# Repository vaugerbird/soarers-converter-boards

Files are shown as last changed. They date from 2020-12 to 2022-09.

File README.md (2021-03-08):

# Soarers-Dongle

Like the description says, this is just a simple dongle adapter for converting an IBM Model M with RJ45 plug to USB through various methods. I whiped up the PCBs in about an hour each, so there might be errors in the PCB design. If there is, file an issue report and I'll fix it right away! Also, please do not plug an ethernet cord into the dongle or keypad, as it might do weird things (or nothing at all)! 

<br>

I've included the EAGLE PCB files for all of the boards, their respective BOMs, and all of Soarer's files relevent to the PCBs. I <i><b>in no way take</b></i> responsibity for creating or modifying the files in the soarers-files folder, all credit goes to Soarer. If you want more info on the original project, check out Soarer's guide [here](https://deskthority.net/viewtopic.php?f=7&t=2510&start=).

TODO
------
To view what needs to be done and what has been done, check out my [Trello](https://trello.com/b/eKjTxFPa/soarers-converter-boards) board!

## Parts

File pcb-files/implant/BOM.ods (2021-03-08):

Part Description | Part # | Mouser # | Digikey # | Footprint | $/Unit | Qty # | Board ID # | Mouser Link | Digikey Link | Notes
ATMega32u4 | ATMEGA32U4-MU | 556-ATMEGA32U4-MU | ATMEGA32U4-AURCT-ND | QFN-44 | $3.98 | 1 | N/A | Mouser (https://www.mouser.com/ProductDetail/Microchip-Technology-Atmel/ATMEGA32U4-MU?qs=JV7lzlMm3yJYRpi0cY3cKw%3D%3D) | Digikey (https://www.digikey.com/en/products/detail/microchip-technology/ATMEGA32U4-AUR/2238241) | Had to change from AU to MU to fit PCB
USB C Port | USB4085-GF-A | N/A | 2073-USB4085-GF-ACT-ND | N/A | $1.34 | 1 | USB-C | N/A | Digikey (https://www.digikey.com/en/products/detail/gct/USB4085-GF-A/9859662)
5.1k Pull-Down Resistor | CRCW06035K10KKEATR | 71-CRCW06035K10KKEAT | SR0603KR-075K1L-ND | 0603 | $0.37 | 1 | R1 | Mouser (https://www.mouser.com/ProductDetail/Vishay-Dale/CRCW06035K10KKEATR?qs=V3IlGBufnyVplw9ReaVc8A%3D%3D) | Digikey (https://www.digikey.com/en/products/detail/yageo/SR0603KR-075K1L/5948489) | Minimum order of 5000 from Digi
22 Ohm Data Resistor | RS73G2ATTD22R0B | 660-RS73G2ATTD22R0B | 2019-RS73G2ATTD22R0BTR-ND | 0805 | $0.52 | 2 | R2, R3 | Mouser (https://www.mouser.com/ProductDetail/KOA-Speer/RS73G2ATTD22R0B?qs=YwPsRIUVAOdxbc5%2F8NI5WA%3D%3D) | Digikey (https://www.digikey.com/en/products/detail/koa-speer-electronics-inc/RS73G2ATTD22R0B/11573620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) | Minimum order of 5000 from Digi
1uF Capacitor | C0805C105M5PACTU | 80-C0805C105M5P | N/A | 0805 | $0.76 | 1 | C1 | Mouser (https://www.mouser.com/ProductDetail/KEMET/C0805C105M5PACTU?qs=Mv1qlCsH0%252BHK4n8YpZMO7w%3D%3D) | N/A
5V 500mA Regulator | TPS7A2650DRVR | 595-TPS7A2650DRVR |  | WSON-6 | $1.00 | 1 |  | Mouser (https://www.mouser.com/ProductDetail/Texas-Instruments/TPS7A2650DRVR?qs=OTrKUuiFdkaeaXj%2F%252BB59oA%3D%3D)

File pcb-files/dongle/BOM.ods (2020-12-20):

Part Description | Part # | Mouser # | Digikey # | Footprint | $/Unit | Qty # | Board ID # | Mouser Link | Digikey Link | Notes
ATMega32u4 | ATMEGA32U4-AUR | 556-ATMEGA32U4-AUR | ATMEGA32U4-AURCT-ND | TQFP-44 | $4.08 | 1 |  | Mouser (https://www.mouser.com/ProductDetail/Microchip-Technology-Atmel/ATMEGA32U4-AUR/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) | Digikey (https://www.digikey.com/en/products/detail/microchip-technology/ATMEGA32U4-AUR/2238241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)
RJ45 Jack | SS-60300-046 | 530-SS-60300-046 | 380-1386-ND | N/A | $2.08 | 1 |  | Mouser (https://www.mouser.com/ProductDetail/Stewart-Connector-Bel/SS-60300-046/?qs=1mbolxNpo8eTkIf8KSQsmg%3D%3D) | Digikey (https://www.digikey.com/en/products/detail/stewart-connector/SS-60300-046/7691008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)
22 Ohm Data Resistor | RS73G2ATTD22R0B | 660-RS73G2ATTD22R0B | 2019-RS73G2ATTD22R0BTR-ND | 0805 | $0.52 | 2 | R2, R3 | Mouser (https://www.mouser.com/ProductDetail/KOA-Speer/RS73G2ATTD22R0B?qs=YwPsRIUVAOdxbc5%2F8NI5WA%3D%3D) | Digikey (https://www.digikey.com/en/products/detail/koa-speer-electronics-inc/RS73G2ATTD22R0B/11573620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) | Minimum order of 5000 from Digi
1uF Capacitor | C0805C105M5PACTU | 80-C0805C105M5P | N/A | 0805 | $0.76 | 1 | C1 | Mouser (https://www.mouser.com/ProductDetail/KEMET/C0805C105M5PACTU?qs=Mv1qlCsH0%252BHK4n8YpZMO7w%3D%3D) | N/A
USB Plug | KUSBX-SMT2AP5S-B | 806-KUSBXSMT2AP5SB |  | N/A | $1.10 | 1 |  | Mouser (https://www.mouser.com/ProductDetail/Kycon/KUSBX-SMT2AP5S-B/?qs=7zcQ9RRVJlhCJlshlB7IBQ%3D%3D) |  | Don’t like this plug, might find different

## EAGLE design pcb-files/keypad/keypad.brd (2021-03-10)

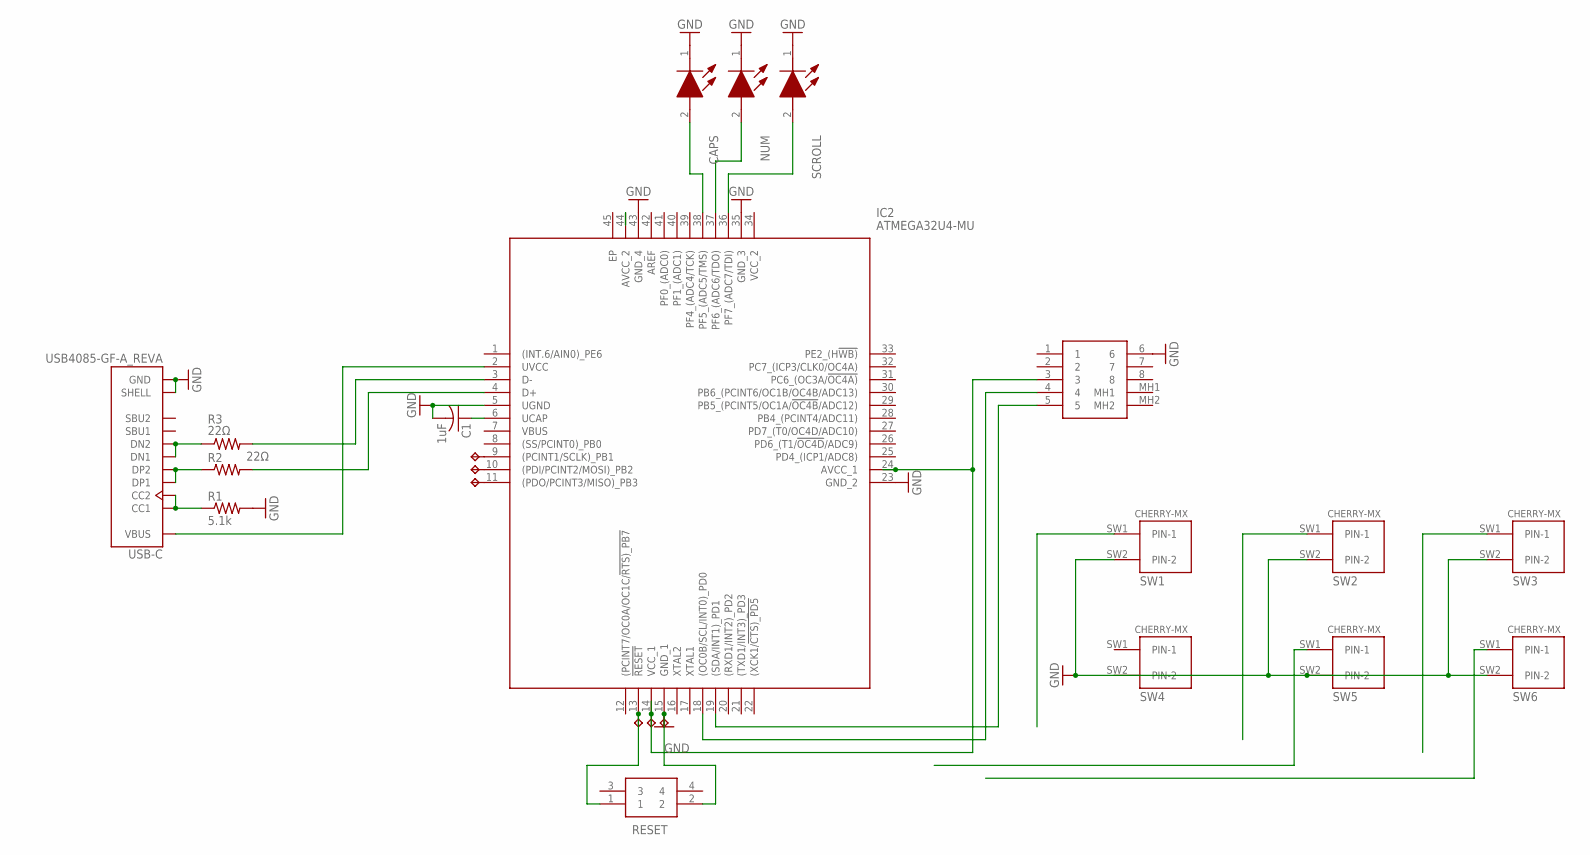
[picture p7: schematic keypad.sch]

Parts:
5V: TPTP17R; TP17R
C1: 1uF; C0805
CAPS: 155060GS75300
GND: TPTP17R; TP17R
IC2: ATMEGA32U4-MU; QFN50P700X700X100-45N
J2: SS-60300-046; SS60300046
MISO: TPTP17R; TP17R
MOSI: TPTP17R; TP17R
NUM: 155060GS75300
R1: 5.1k; R0603
R2, R3: 22Ω; R0805
RESET: LL3303F065QG
RST: TPTP17R; TP17R
SCLK: TPTP17R; TP17R
SCROLL: 155060GS75300
SW1, SW2, SW3, SW4, SW5, SW6: CHERRY-MX
USB-C: USB4085-GF-A_REVA; GCT_USB4085-GF-A_REVA

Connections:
CAPS: CAPS.2 (A), IC2.38 (PF5_(ADC5/TMS))
CC: R1.1, USB-C.A5 (CC1), USB-C.B5 (CC2)
CLK: IC2.19 ((SDA/INT1)_PD1), J2.5
D+: R2.1, USB-C.A6 (DP1), USB-C.B6 (DP2)
D+RES: IC2.4 (D+), R2.2
D-: R3.1, USB-C.A7 (DN1), USB-C.B7 (DN2)
D-RES: IC2.3 (D-), R3.2
DATA: IC2.18 ((OC0B/SCL/INT0)_PD0), J2.4
GND: C1.2, CAPS.1 (K), GND.TP, IC2.5 (UGND), IC2.15 (GND_1), IC2.23 (GND_2), IC2.35 (GND_3), IC2.43 (GND_4), J2.6, NUM.1 (K), R1.2, RESET.2, SCROLL.1 (K), SW1.SW2 (PIN-2), SW2.SW2 (PIN-2), SW3.SW2 (PIN-2), SW4.SW2 (PIN-2), SW5.SW2 (PIN-2), SW6.SW2 (PIN-2), USB-C.A1 (GND), USB-C.A12 (GND), USB-C.B1 (GND), USB-C.B12 (GND), USB-C.P1 (SHELL), USB-C.P2 (SHELL), USB-C.P3 (SHELL), USB-C.P4 (SHELL)
MISO: IC2.11 ((PDO/PCINT3/MISO)_PB3), MISO.TP
MOSI: IC2.10 ((PDI/PCINT2/MOSI)_PB2), MOSI.TP
NUM: IC2.37 (PF6_(ADC6/TDO)), NUM.2 (A)
RESET: IC2.13 (!RESET), RESET.1, RST.TP
SCLK: IC2.9 ((PCINT1/SCLK)_PB1), SCLK.TP
SCRL: IC2.36 (PF7_(ADC7/TDI)), SCROLL.2 (A)
SW1: SW1.SW1 (PIN-1)
SW2: SW2.SW1 (PIN-1)
SW3: SW3.SW1 (PIN-1)
SW5: SW5.SW1 (PIN-1)
SW6: SW6.SW1 (PIN-1)
UCAP: C1.1, IC2.6 (UCAP)
VCC: 5V.TP, IC2.14 (VCC_1), IC2.24 (AVCC_1), IC2.44 (AVCC_2), J2.3
VIN: IC2.2 (UVCC), USB-C.A4 (VBUS), USB-C.A9 (VBUS), USB-C.B4 (VBUS), USB-C.B9 (VBUS)

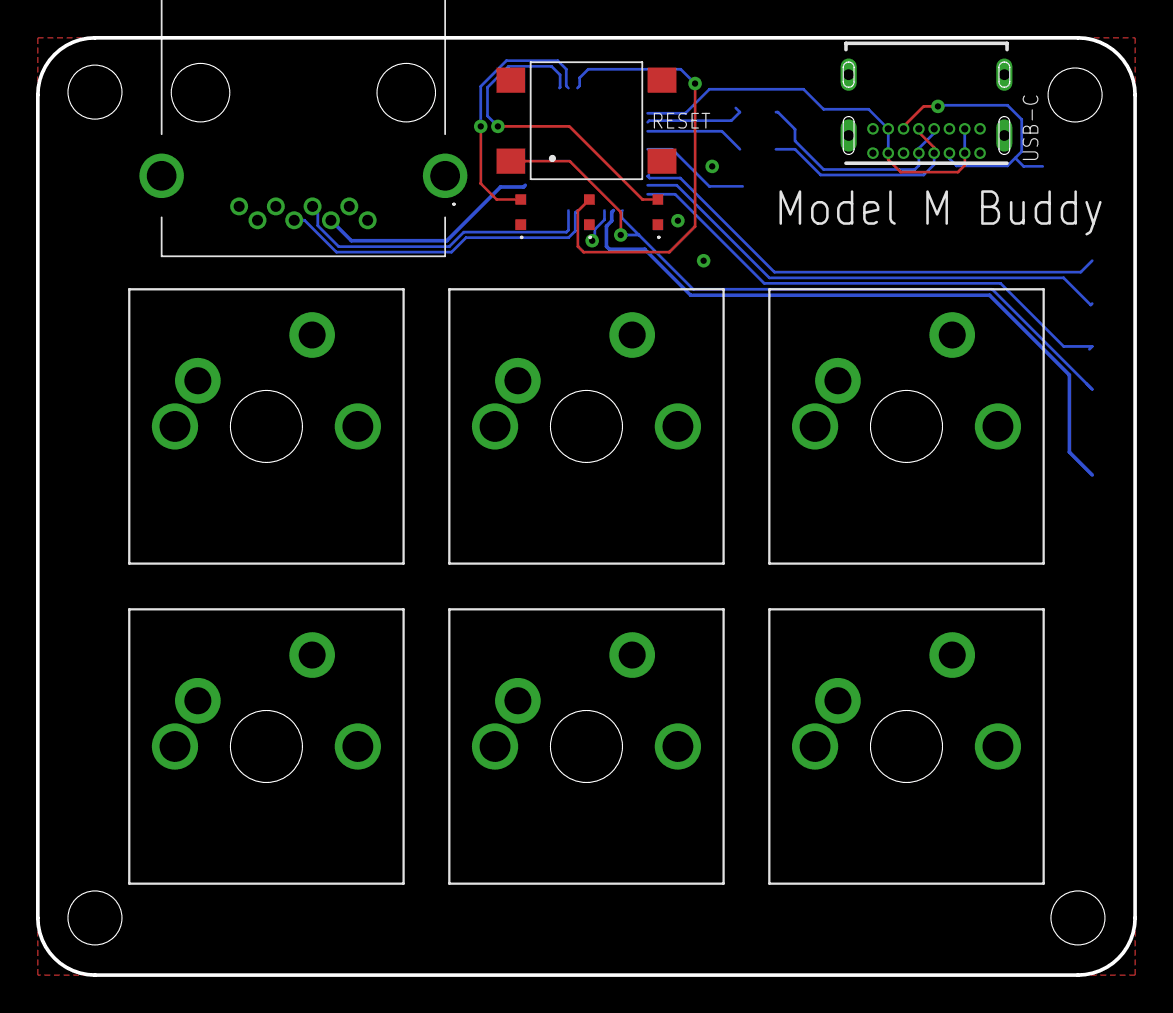
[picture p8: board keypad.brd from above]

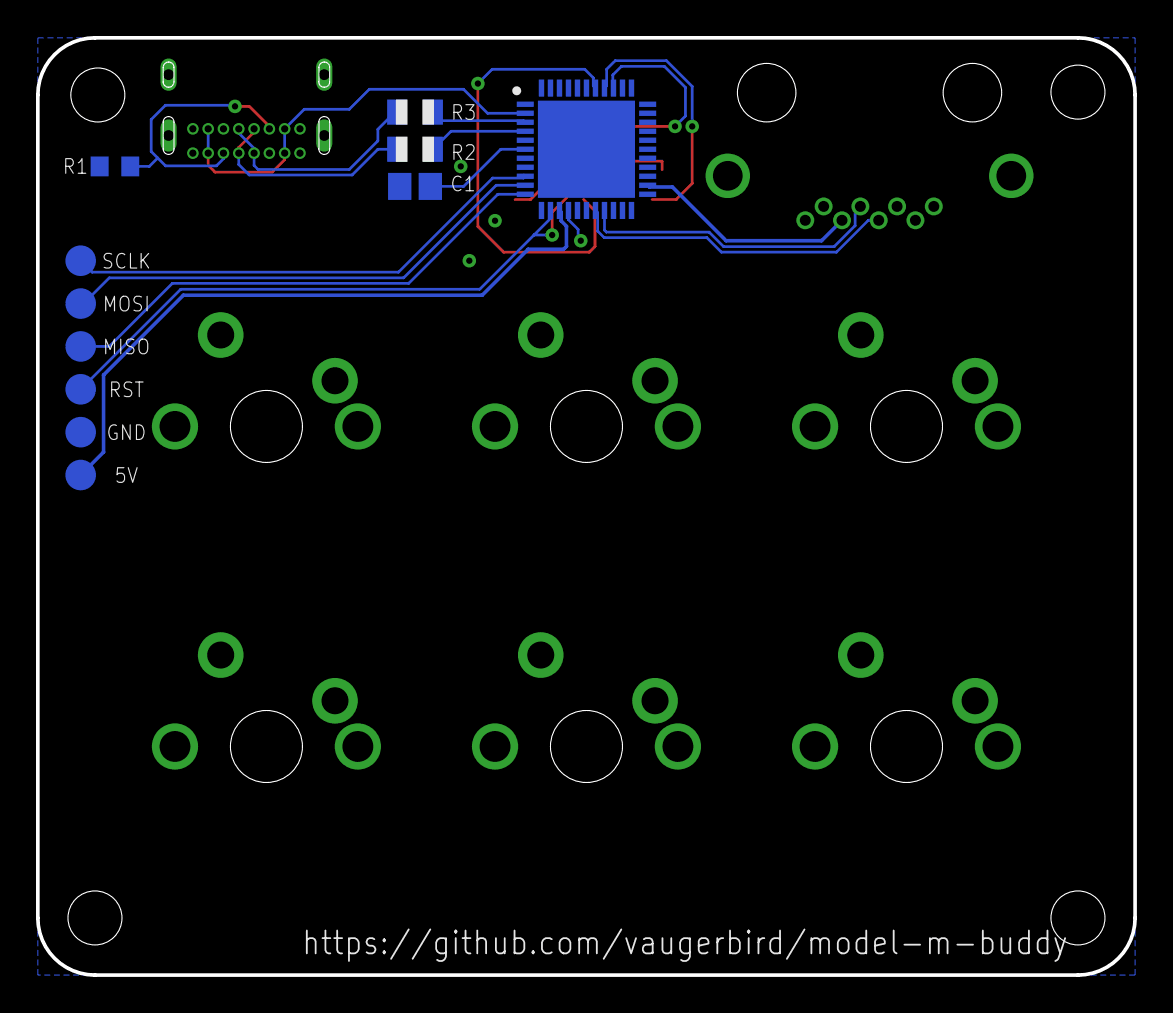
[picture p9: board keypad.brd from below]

Board: 2 copper layers, 61.0 x 52.1 mm, 23 parts (11 on the bottom side), 18 nets.

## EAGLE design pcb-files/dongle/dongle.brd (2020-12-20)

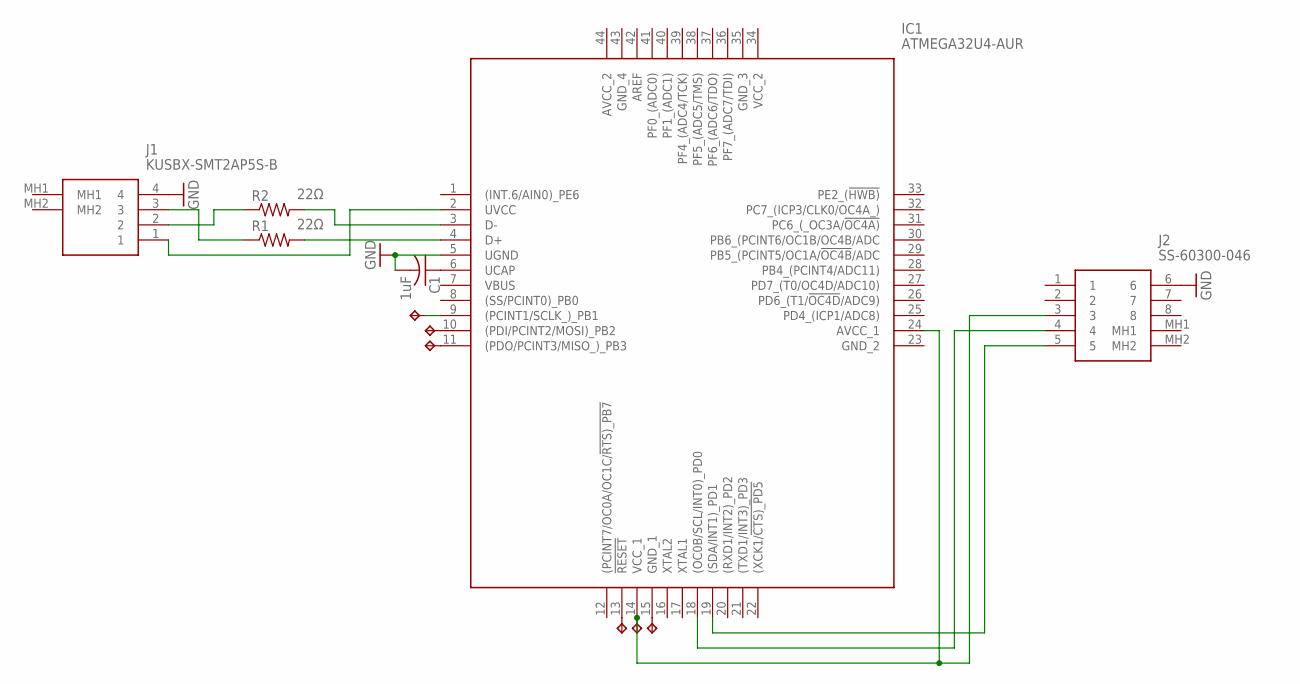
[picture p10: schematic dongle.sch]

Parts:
5V: TPTP17R; TP17R
C1: 1uF; C0805
GND: TPTP17R; TP17R
IC1: ATMEGA32U4-AUR; QFP80P1200X1200X120-44N
J1: KUSBX-SMT2AP5S-B; KUSBXSMT2AP5SB
J2: SS-60300-046; SS60300046
MISO: TPTP17R; TP17R
MOSI: TPTP17R; TP17R
R1, R2: 22Ω; R0805
RST: TPTP17R; TP17R
SCLK: TPTP17R; TP17R

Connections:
CLK: IC1.19 ((SDA/INT1)_PD1), J2.5
D+: J1.3, R1.1
D+RES: IC1.4 (D+), R1.2
D-: J1.2, R2.1
D-RES: IC1.3 (D-), R2.2
DATA: IC1.18 ((OC0B/SCL/INT0)_PD0), J2.4
GND: C1.2, GND.TP, IC1.5 (UGND), IC1.15 (GND_1), J1.4, J2.6
MISO: IC1.11 ((PDO/PCINT3/MISO_)_PB3), MISO.TP
MOSI: IC1.10 ((PDI/PCINT2/MOSI)_PB2), MOSI.TP
RST: IC1.13 (!RESET), RST.TP
SCLK: IC1.9 ((PCINT1/SCLK_)_PB1), SCLK.TP
UCAP: C1.1, IC1.6 (UCAP)
VCC: 5V.TP, IC1.14 (VCC_1), IC1.24 (AVCC_1), J2.3
VIN: IC1.2 (UVCC), J1.1

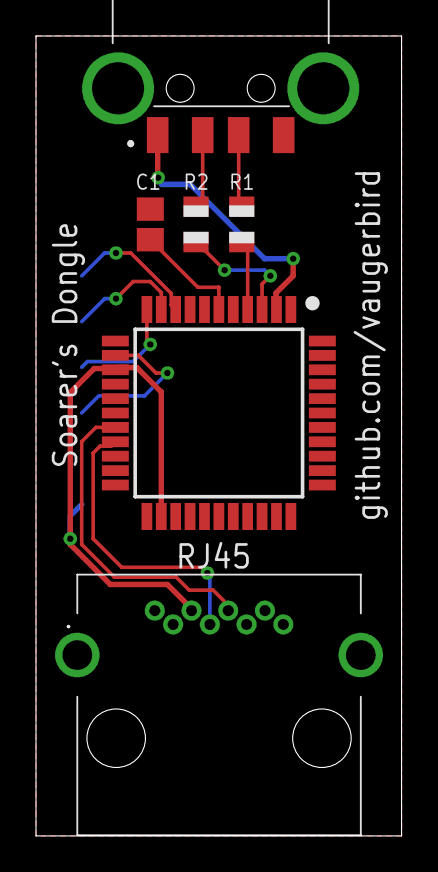
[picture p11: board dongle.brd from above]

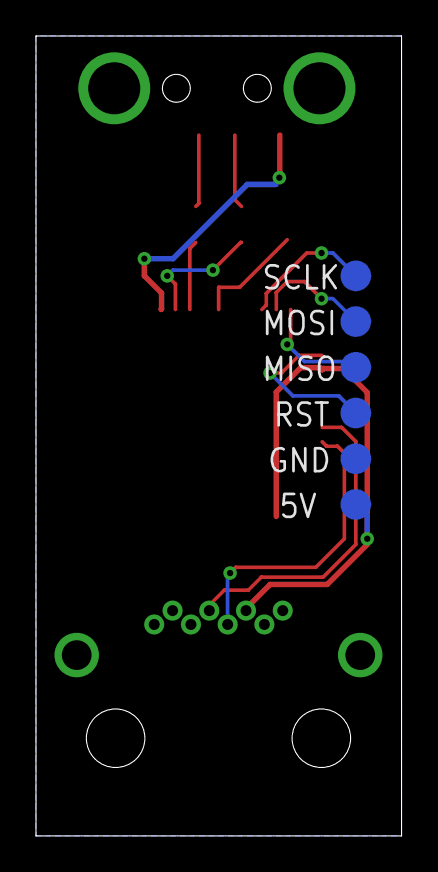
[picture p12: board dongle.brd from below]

Board: 2 copper layers, 20.3 x 44.4 mm, 12 parts (6 on the bottom side), 14 nets.

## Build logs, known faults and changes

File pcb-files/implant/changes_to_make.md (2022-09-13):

1. Change USB-C port: https://www.mouser.com/ProductDetail/GCT/USB4105-GF-A?qs=KUoIvG%2F9IlY%2FMLlBMpStpA%3D%3D
2. Add some more annotations
3. Might need to add diode to voltage regulator
4. Increase trace size
5. Ensure proper CC resistor

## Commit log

2020-12-20 Create PCB files and BOM
    [BOM.ods, dongle.brd, dongle.sch]
2020-12-20 Add finished PCB and BOM
    [BOM.ods, dongle.brd, dongle.sch]
2020-12-20 Make Gerber
    [BOM.ods]
2020-12-20 Update PCB with better USB placement
    [BOM.ods]
2020-12-20 Update PCB
    [dongle.brd]
2021-01-07 Fix BOM
    [BOM.ods]
2021-03-08 Combine model-m-buddy and soarers-dongle
    [BOM.ods, dongle.brd, dongle.sch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]
2021-03-08 Workin on the implant
    [BOM.ods, mmimplant.brd, mmimplant.sch]
2021-03-09 Finishing touches on implant + gerber
    [mmimplant.brd, mmimplant.sch]
2021-03-09 Just some renaming
    [implant.brd, implant.sch]
2021-03-10 Finished the last board design
    [keypad.brd, keypad.sch]
